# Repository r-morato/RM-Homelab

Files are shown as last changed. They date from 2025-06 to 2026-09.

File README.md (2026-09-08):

# RM-Homelab




A compact, quiet, movable homelab in a custom 10-inch rack - two cables to run it
(power and Ethernet), enough capability to host the services I use every day, and
built so a single hardware failure or a bad upgrade doesn't take anything down for long.

This repo documents **how it works**: the cluster, the storage and replication model,
backups, the automation that patches everything, and the security choices. It is written
so I can rebuild from it.

> **Addresses and hostnames in this repo are sanitised.** `10.0.0.x` is the LAN /
> management segment, `10.0.1.x` the storage + cluster segment, and hostnames are
> generic labels (`pve-node-1`, `ct-dashboard`, …). Real values live only in a
> gitignored inventory on the host.

## Why build it

I wanted one place to learn, experiment, and self-host - with real control over my data
and no monthly bill for things I can run myself. The constraints that shaped every
decision: **low noise** (it lives near people), **low power**, **physically mobile**
(hence wheels), and **cheap** - no enterprise hardware. Not the most powerful lab; the
sweet spot between capability, cost, and cleanliness.

## What it is now

- **2-node Proxmox VE cluster** (a Lenovo ThinkCentre M720q and an HP EliteDesk 800
  mini-PC) with an external **QDevice** on the NAS for quorum.
- **High availability across every running guest** - lose a node and everything restarts
  on the other in a few minutes, then moves home when the node returns.
- **Shared storage over NFS from the NAS** - guest disks live there so either node can
  run any guest.
- **Nightly backups to the NAS** - `vzdump` for the stateful containers, a daily
  host-config archive, and a database-consistent dump for the one guest that needs it.
  Restores are tested.
- **Scheduled, hands-off patching** - a dedicated Ansible container with a
  [Semaphore](https://github.com/semaphoreui/semaphore) web UI patches the containers
  weekly and the hypervisors monthly, and pushes a summary to my phone. Reboots stay
  manual.
- **Hardened baseline** - key-only SSH with `fail2ban`, the Docker API on a local socket
  only, secrets kept out of git, and a staged firewall rollout.

## Documentation

| | |
|---|---|
| [Architecture](docs/architecture.md) | how it all fits together - nodes, guests, storage, boot order |
| [High availability & replication](docs/high-availability.md) | quorum on 2 nodes, HA failover, planned-maintenance drains |
| [Storage](docs/storage.md) | the NFS / local-lvm / media-NAS tiers and the trade-offs |
| [Networking](docs/networking.md) | the two segments, addressing, DNS, the corosync caveat |
| [Backups](docs/backups.md) | the `vzdump` job, host-config backup, the DB hook, restore test |
| [Automation](docs/automation.md) | the Ansible + Semaphore control container and repo |
| [Automated patching](docs/patching.md) | the "patch on schedule, notify-to-reboot" model |
| [Provisioning & configuration](docs/provisioning.md) | how a new guest is built and wired in |
| [Security](docs/security.md) | SSH, isolation, service exposure, the firewall plan |
| [Ansible playbooks](ansible/) | the actual automation code, with its own README |
| [Rack build](rack-build.md) | the custom 10-inch enclosure |
| [Hardware](hardware/) · [Software](software/) | per-component notes |
| [Diagrams](diagrams/) · [3D prints](3d_prints/) | network + cluster diagrams, printed mounts |

## Hardware at a glance

| Component | Role |
|---|---|
| Lenovo ThinkCentre M720q Tiny | Proxmox VE cluster node 1 (primary) |
| HP EliteDesk 800 (Mini) | Proxmox VE cluster node 2 (failover) |
| NAS (mirrored disks) | NFS shared storage, backup target, corosync QDevice |
| Raspberry Pi 4 | Home Assistant OS (bare metal, outside the cluster) |
| ESP32 + e-ink display | Proxmox stats display on the rack |
| Mac Mini | jump box / daily driver |
| TP-Link TL-SG108S | 8-port gigabit switch (unmanaged) |
| Eero Mesh 6 | router / gateway / Wi-Fi |
| APC Back-UPS 300W | battery backup |
| Oimaster HE-2006 + PCIe SATA card | hot-swap SSD bays |
| Hive Hub | heating control (Home Assistant integration) |

Full notes in [`hardware/`](hardware/) and [`rack-build.md`](rack-build.md).

## Lessons learned

- **Noise matters more than you think** when servers live near bedrooms.
- **Cheap gear goes surprisingly far** if you're willing to tinker.
- **Power and thermals aren't optional** - the SSDs show a high unclean-shutdown count,
  which is why a UPS with automatic graceful shutdown is near the top of the list.
- **A 2-node cluster needs a third vote.** Without the QDevice, losing either node
  freezes the survivor. With it, failover is a non-event.
- **`curl | bash` from someone else's `main` branch, as root, on a schedule** is a bad
  idea however convenient - replacing it with version-controlled Ansible was worth it.
- **Snapshots and tested restores turn mistakes into footnotes.**

## Roadmap

- Off-NAS / offsite copy of the backup archives (currently the biggest gap).
- Finish the staged Proxmox firewall rollout (see [security](docs/security.md)).
- Second corosync link so the heartbeat doesn't share one wire with NFS.
- Move small stateful containers onto local storage for snapshot-mode backups.
- 2FA on the Proxmox admin account and Semaphore.
- Dynamic Ansible inventory from the PVE API.
- More Home Assistant sensors and automations.

## License

[MIT](LICENSE) © Roger Morato

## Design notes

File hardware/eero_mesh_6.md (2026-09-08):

# Eero Mesh 6 - router / gateway

The perimeter router and Wi-Fi for the whole house, including the lab. `10.0.0.1` on the
LAN segment.

## Role

* **Gateway / NAT** - the only path to the internet.
* **DHCP** for dynamic clients; static infra addresses sit outside the pool.
* **Perimeter firewall** - the only packet filtering currently in effect (the Proxmox
  firewall is designed but not enabled - see [`docs/security.md`](../docs/security.md)).
* **Wi-Fi 6 mesh** for phones, laptops, smart-home gear, and the ESP32 display.

## Notes

* No ports are forwarded to the lab. Remote access is via
  [Guacamole](../software/guacamole.md) or a VPN.
* Its presence is picked up by Home Assistant for device presence detection.
* A dedicated x86 firewall/router appliance (OPNsense-class) is a long-standing "maybe"
  - it would also give real VLAN support.

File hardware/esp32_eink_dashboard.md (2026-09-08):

# ESP32 + e-ink Proxmox dashboard

A small battery-friendly wall display on the rack that shows cluster stats at a glance - node load, memory, guest count, backup age - without opening a browser.

## Build

| | |
|---|---|
| MCU | ESP32 (Wi-Fi) |
| Display | e-ink panel - near-zero power when static, readable in any light |
| Power | USB from the rack's 6-port charger |
| Mount | custom 3D-printed bracket sized to the panel (not yet published) |

## How it works

The ESP32 connects to Wi-Fi, calls the **Proxmox VE API** read-only (a dedicated token
user with view-only permissions), parses the JSON, and redraws the e-ink panel on an
interval. Between refreshes it deep-sleeps, so it sips power.

It is **outside the cluster** and purely a consumer of the API - nothing depends on it,
and it has no write access.

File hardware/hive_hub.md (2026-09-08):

# Hive Hub - heating control

The manufacturer hub for the home's Hive smart heating (thermostat + schedule). Powered
from the rack's 6-port USB charger, sat on top of the rack to keep its radio clear of
the metal.

## Role

* Talks to the Hive thermostat and receiver over its own radio.
* Bridged into [Home Assistant](../software/homeassistant.md) via the Hive integration,
  so heating is part of presence- and schedule-driven automations rather than a
  separate app.

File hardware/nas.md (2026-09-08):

# NAS - shared storage, backup target & QDevice

A low-power, always-on network-attached storage box that does three jobs for the
cluster. It is the most load-bearing single device in the lab.

## The three roles

1. **Shared storage over NFS.** It exports a filesystem that both cluster nodes mount as
   `PROX-NFS`. Every guest's root disk is a raw image on that export - which is what lets
   either node start any guest, and therefore what makes HA failover possible on a
   cluster with no shared block storage. See [storage](../docs/storage.md).
2. **Backup target.** The nightly `vzdump` archives and the daily host-config archives
   land on the same export. See [backups](../docs/backups.md).
3. **Cluster QDevice.** It runs `corosync-qnetd`, providing the third quorum vote so the
   2-node cluster stays quorate when a node is down. See
   [high availability](../docs/high-availability.md) and [`qdevice-host.md`](qdevice-host.md).

## Configuration

| | |
|---|---|
| Disks | 2 × HDD, **mirrored** (RAID-1) |
| OS media | separate from the data array - a card / small device, so the data survives an OS-media failure and can be re-assembled independently |
| Filesystem | EXT4 on the mirror |
| Network | on the storage/cluster segment (`10.0.1.x`); NFS export is restricted to that subnet |
| Free space | ~800 GB headroom for backups |

## Why this is a deliberate risk

Mirrored disks protect against a **drive** failure. They do not protect against the
**box** failing, a filesystem bug, or an accidental delete - and if this box goes down,
every guest's root disk vanishes at once and the NFS mount blocks (`hard` mount) until
it's back.

This is accepted because the box has been reliable, restores onto local storage are
tested, and the control container that can rebuild everything is deliberately **not** on
NFS. The open mitigation is a copy of the backup archives that doesn't live on this box - see the gap noted in [storage](../docs/storage.md) and [backups](../docs/backups.md).

## A second NAS

There is a second, larger NAS for the bulk media library, bind-mounted into the media
containers. It is currently **offline**; it is also the intended destination for the
off-box backup copy once it's back in service.

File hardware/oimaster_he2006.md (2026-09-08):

# Oimaster HE-2006 - 4-slot hot-swap SATA cage

A 4-bay internal hot-swap drive cage (3.5" slots, 2.5" SSDs via adapters, individual
power indicators) fitted to [`pve-node-1`](thinkcentre_m720q.md).

## Role

Gives the ThinkCentre - which has almost no internal drive room - accessible,
tool-less SATA bays for 2.5" SSDs, connected through the
[PCIe SATA card](pcie_sata_card.md).

## Notes

The cluster's live guest disks are on **NFS from the [NAS](nas.md)**, and each node
boots from its internal NVMe, so these bays are spare capacity / local scratch rather
than primary storage. They're the obvious place to land guest disks if the design moves
stateful containers onto local storage (see [`docs/storage.md`](../docs/storage.md)).

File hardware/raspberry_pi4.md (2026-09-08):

# Raspberry Pi 4 - Home Assistant

A Raspberry Pi 4 (8 GB) running **Home Assistant OS on bare metal**, powered from the
rack's 6-port USB charger and mounted in a custom 3D-printed 10-inch bracket.

## Why bare metal, outside the cluster

Home automation should keep working while the Proxmox cluster is being patched, rebooted,
or rebuilt - and it needs a stable USB path to the Zigbee coordinator. Running it on its
own dedicated board keeps it independent of everything else in the rack. It has its own
backup routine (HAOS snapshots) separate from the cluster's `vzdump` job.

## Role

* **Home automation hub** - the single control point for the house's smart devices.
* **Zigbee coordinator** - via a Sonoff Zigbee 3.0 USB Dongle Plus, for local
  (cloud-free) control of sensors, lights, and switches.

## Integrations

Zigbee (Sonoff dongle), Hive heating ([`hive_hub.md`](hive_hub.md)), Ecovacs, Ring,
Octopus Energy, LG webOS TV, Spotify, Tuya, the Eero router (presence detection), and
the Home Assistant mobile apps. Plus the usual core integrations (`sun`, `met` weather,
`cast`, Supervisor, `backup`).

See [`software/homeassistant.md`](../software/homeassistant.md) for the platform side.

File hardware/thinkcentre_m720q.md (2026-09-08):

# Lenovo ThinkCentre M720q Tiny - `pve-node-1`

The primary node of the [Proxmox VE cluster](../software/proxmox.md). An ultra-compact
1-litre business desktop - quiet, low-power, and cheap on the used market, which is the
whole point of this build.

## Role

* **Primary cluster node.** The HA node-affinity rule prefers it, so all guests normally
  run here and [`pve-node-2`](pve-node-2.md) sits idle as failover.
* Hosts the integrated GPU that [`ct-media-a`](../software/jellyfin.md) and
  [`ct-media-b`](../software/plex.md) share for hardware transcoding.
* Runs the daily host-config backup timer (see [backups](../docs/backups.md)).

## Configuration

| | |
|---|---|
| CPU | 6-core Intel (no hyper-threading) |
| RAM | 16 GiB DDR4 SODIMM |
| Boot / local storage | single consumer NVMe SSD - LVM root + swap + `local-lvm` thin pool |
| Extra SATA | PCIe → 4-port SATA card into the [Oimaster HE-2006](oimaster_he2006.md) bays |
| Network | onboard NIC (LAN, `vmbr0`) + a second NIC (storage/cluster, `vmbr1`) |
| OS | Proxmox VE 9.2 on Debian 13 |

## Notes

* **Single SSD = no local redundancy.** This is tolerated because the guests' disks live
  on the [NAS](nas.md) over NFS and are backed up; the node itself is reproducible from
  the host-config archive.
* The SSD's SMART data is healthy (low wear, zero media errors) but shows a **high
  unclean-shutdown / power-cycle count** - the reason a UPS with automatic graceful
  shutdown is on the roadmap. See [`apc_ups.md`](apc_ups.md).
* Mounted in the rack on a custom 3D-printed tray - see [`3d_prints/`](../3d_prints/).

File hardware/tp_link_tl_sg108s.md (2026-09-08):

# TP-Link TL-SG108S - 8-port gigabit switch

The wired core of the rack. Unmanaged, plug-and-play, gigabit on all 8 ports.

## Role

Connects everything wired: both cluster nodes (two cables each - one per segment), the
NAS (two cables), the Raspberry Pi, the Mac Mini, and the uplink to the
[Eero](eero_mesh_6.md).

## Consequence of it being unmanaged

No VLANs. The "LAN" and "storage/cluster" segments
([`docs/networking.md`](../docs/networking.md)) therefore share **one L2 broadcast
domain** - separation is logical (different subnets, and each node uses a specific NIC
for storage/corosync traffic), not true isolation. A managed switch with VLANs, or a
direct node-to-node link for corosync, is on the roadmap.

At 8 ports it is also nearly full - the next expansion needs a bigger switch anyway.

## Mounting

Custom 3D-printed 10-inch bracket - see [`3d_prints/`](../3d_prints/).

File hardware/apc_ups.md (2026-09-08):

# APC Back-UPS (300 W / 0.5 kVA)

Line-interactive UPS on the critical leg of the rack: the two cluster nodes, the switch,
the router, and the NAS. It rides out brownouts and short outages and gives everything
time for a clean shutdown on a long one.

## Current state

* **Battery backup and surge protection: working.** A brief power blip is invisible to
  the lab.
* **Automatic graceful shutdown: not wired up yet.** It used to be driven over USB from
  the (now offline) media NAS acting as a master and signalling Proxmox. With that box
  down, there is no automatic "power's been out for N minutes, shut down now" path.

The nodes' SSDs show a high unclean-shutdown count, so restoring this is a priority.

## Plan

Connect the UPS's USB to one cluster node, run **NUT** (`nut-server` there,
`nut-client` on the other node and the NAS), and configure a shutdown policy: on
"battery low" or after a set time on battery, HA guests stop, then the nodes power off.
Everything comes back on its own when mains returns and the nodes `onboot` their guests.

## Powered by the UPS

ThinkCentre (`pve-node-1`), HP EliteDesk (`pve-node-2`), TP-Link switch, Eero router,
NAS. The Raspberry Pi and low-power accessories are on the non-UPS leg.

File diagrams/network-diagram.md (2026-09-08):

# Network diagram

Logical topology. Addresses are sanitised: `10.0.0.x` = LAN / management,
`10.0.1.x` = storage + cluster. See [`docs/networking.md`](../docs/networking.md).

```mermaid
flowchart TB
    ISP([Internet]) --- Router["Eero Mesh 6<br>router / gateway · 10.0.0.1"]
    Router --- SW["TP-Link SG108S<br>8-port unmanaged switch"]

    subgraph LAN["LAN / management - 10.0.0.0/24 (vmbr0)"]
        N1LAN["pve-node-1 · 10.0.0.11"]
        N2LAN["pve-node-2 · 10.0.0.12"]
        Guests["LXC guests<br>10.0.0.100-112"]
        Pi["Raspberry Pi 4<br>Home Assistant OS"]
        ESP["ESP32 e-ink<br>Proxmox stats (Wi-Fi)"]
    end

    subgraph STOR["storage + cluster - 10.0.1.0/24 (vmbr1)"]
        N1S["pve-node-1 · 10.0.1.11"]
        N2S["pve-node-2 · 10.0.1.12"]
        NAS["NAS · 10.0.1.40<br>NFS export + corosync-qnetd (QDevice)"]
    end

    SW --- N1LAN
    SW --- N2LAN
    SW --- Guests
    SW --- Pi
    Router -. Wi-Fi .- ESP
    SW --- N1S
    SW --- N2S
    SW --- NAS

    N1S -- "NFS: guest root disks + backups" --- NAS
    N2S -- NFS --- NAS
    N1S -. "corosync ring + QDevice vote" .- NAS
    N2S -. corosync .- NAS
    N1S === N2S

    ESP -. "PVE API (read-only)" .-> N1LAN
```

Legend: solid = data path, dotted = cluster / control traffic, `===` = corosync between
the two nodes.

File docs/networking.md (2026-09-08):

# Networking

## Two segments, on purpose

| Segment | Subnet (sanitised) | Bridge | Carries |
|---|---|---|---|
| LAN / management | `10.0.0.0/24` | `vmbr0` | guest traffic, the web UIs, SSH, the automation container → targets |
| Storage + cluster | `10.0.1.0/24` | `vmbr1` | NFS to the NAS, corosync, the QDevice vote |

Each node has a physical NIC on each segment. Keeping storage and cluster traffic off
the LAN means a busy download or a Plex transcode pulling from the NAS doesn't compete
with the corosync heartbeat for the same wire - mostly. See the known limitation below.

```
   Router ── Switch ─┬─ pve-node-1 vmbr0 (10.0.0.11)  ── guests, mgmt
                     │  pve-node-1 vmbr1 (10.0.1.11)  ── NFS + corosync
                     ├─ pve-node-2 vmbr0 (10.0.0.12)
                     │  pve-node-2 vmbr1 (10.0.1.12)
                     ├─ NAS         (10.0.1.40)        ── NFS export + corosync-qnetd
                     ├─ Raspberry Pi 4 (10.0.0.x)      ── Home Assistant
                     └─ ESP32 e-ink   (Wi-Fi)          ── Proxmox stats display
```

## Guest addressing

Guests are on `vmbr0` with static addresses in `10.0.0.100`-`10.0.0.112`, chosen to
match the Proxmox VMID (guest `104` is `10.0.0.104`). It makes the inventory readable
and means you can guess a guest's address from its ID. The automation container is
`10.0.0.109`.

## The router and DNS

* The perimeter router / gateway is an **Eero mesh** (`10.0.0.1`) doing DHCP for
  dynamic clients, NAT, and the basic firewall. Static infra addresses are outside the
  DHCP pool. See [`hardware/eero_mesh_6.md`](../hardware/eero_mesh_6.md).
* **Pi-hole** provides LAN DNS and ad/tracker filtering; clients are pointed at it
  either by DHCP option or per-device. See [`software/pihole.md`](../software/pihole.md).
* The 8-port unmanaged switch ([`hardware/tp_link_tl_sg108s.md`](../hardware/tp_link_tl_sg108s.md))
  is the wired core. Because it's unmanaged there are **no VLANs**: the two segments
  share one L2 broadcast domain, and the separation is only logical - different subnets,
  and each node using a specific NIC for storage/corosync. True isolation (a managed
  switch + VLANs, or a direct node-to-node corosync link) is a roadmap item.

## Corosync - the known weak spot

Corosync currently runs a **single ring** on the storage segment. That is a
simplification worth calling out:

* If that link flaps, or NFS saturates it badly enough to delay heartbeats, corosync
  sees a membership change even though both nodes are healthy.
* **Roadmap:** add a second `knet` link on the LAN segment so corosync has a fallback
  path, and ideally make a dedicated NIC the primary ring.

Until then the QDevice is what keeps a spurious membership blip from turning into a
loss of quorum - see [high availability](high-availability.md).

## Firewall posture

The Proxmox firewall is being rolled out in stages - datacenter default-deny inbound,
management ports restricted to one subnet, per-guest app-port rules - described in
[security](security.md). Perimeter filtering is handled by the Eero in the meantime.

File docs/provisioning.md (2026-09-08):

# Provisioning & configuration

How a new service goes from "I want to run X" to "X is running, backed up, HA-managed,
and patched on schedule."

## Guest defaults

Every guest is an **unprivileged LXC container**. VMs are avoided unless something needs
its own kernel - containers are lighter, boot in a second, and share the host's patched
kernel.

| Setting | Default | Notes |
|---|---|---|
| Type | unprivileged LXC | UID-remapped; a root break-out lands as an unprivileged host UID |
| `onboot` | `1` | HA starts it anyway, but this covers a single-node boot |
| `features` | `nesting=0,keyctl=0` | **only** the Docker host gets `nesting=1` |
| Root disk | raw image on `PROX-NFS` | so either node can start it - except the control container, which is on `local-lvm` |
| Network | static on `vmbr0`, `10.0.0.<vmid>` | address matches the VMID |
| Firewall | `firewall=1` | per-guest firewall enabled (rules come with the firewall rollout) |

The current fleet is a mix of Debian 13 / 12 and Ubuntu 24.04. New guests are Debian 13.

## Steps to add a service

1. **Create the container** - from the Debian 13 template, with the defaults above.
   `ct-dashboard`-style config lives in the container; nothing about the app goes in the
   Proxmox guest config except a Notes reference (see below).
2. **Put it under HA** - `ha-manager add ct:<id> --state started`, then add `ct:<id>` to
   the node-affinity rule so it prefers `pve-node-1` with `pve-node-2` as failover. See
   [high availability](high-availability.md).
3. **Add it to backups if it holds unique state** - add the VMID to the nightly `vzdump`
   job and to the `backup_protected` group in the Ansible inventory. Streaming /
   download / indexer containers are deliberately left off - see [backups](backups.md).
4. **Wire up the automation** - add it to `inventory/hosts.yml` (and the Semaphore static
   inventory), authorise the control-container key, add the `20-ansible.conf` sshd
   drop-in if the guest uses `AllowUsers`. Full steps in [automation](automation.md).
5. **Harden its SSH** - key-only root, `PasswordAuthentication no`, `fail2ban`. See
   [security](security.md).

## The Notes-field convention

Each guest's Proxmox **Notes** field carries a short plaintext reference - the service
URL and port, the config path inside the container, and a pointer to where credentials
are kept (a password manager). It does **not** carry the credentials themselves.

Notes fields are visible through the web UI and API and are included in every config
backup, so anything written there should be treated as non-secret. The rule: Notes
describe *where things are*, never *what the secrets are*.

## GPU passthrough (media containers)

`ct-media-a` (Jellyfin) and `ct-media-b` (Plex) share the host's integrated GPU for
hardware transcoding: the render device is bind-mounted into the container and the
container's media user is put in the right group. Both containers can use it at once
(it's shared, not exclusive-passthrough), which is fine for a couple of simultaneous
transcodes.

## Bind mounts

The media containers bind-mount the bulk media library from the (currently offline)
media NAS. A bind mount is host-path → container-path and is set on the guest config,
so it has to exist on **whichever node runs the guest** - worth remembering for HA
failover.

## Configuration management, honestly

Application configuration inside the containers is currently **hand-managed** - set up
once, then patched in place. Ansible manages the *fleet* (patching, SSH, soon firewall
rules) but not per-app config. Bringing individual services under a role
(`deploy_docker_service`-style) is a direction, not a current state.

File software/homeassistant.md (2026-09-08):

# Home Assistant

Open-source, local-first home automation platform - the central brain for the house's
smart devices. Runs on **Home Assistant OS, bare metal, on a dedicated
[Raspberry Pi 4](../hardware/raspberry_pi4.md)** - deliberately **outside** the Proxmox
cluster.

## Why it's not a cluster guest

* Home automation should keep working while the cluster is being patched or rebuilt.
* It needs a stable, exclusive USB path to the Zigbee coordinator - cleaner on dedicated
  hardware than passed through to a container.
* It has its own backup story (HAOS snapshots), independent of the cluster's `vzdump`.

## Role

* **Single control surface** for every smart device, regardless of brand.
* **Local Zigbee network** via a Sonoff Zigbee 3.0 USB Dongle Plus - sensors, lights,
  switches, no cloud round-trip.
* **Automation engine** - presence- and sensor-driven routines (heating, lighting,
  notifications).
* **Dashboards & history** for sensor data and energy use.

## Integrations

Zigbee, Hive heating, Ecovacs, Ring, Octopus Energy, LG webOS TV, Spotify, Tuya, the
Eero router (presence), and the Home Assistant mobile apps.

## Relationship to the lab

Monitored by [Uptime Kuma](uptimekuma.md); resolves DNS through [Pi-hole](pihole.md).
Otherwise self-contained.

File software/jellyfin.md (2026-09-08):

# Jellyfin

Open-source media server. Runs in `ct-media-a` (VMID 102).

## Role

* Streams the media library (stored on the media NAS, bind-mounted into the container)
  to clients on the LAN and remotely.
* The free/self-hosted counterpart to [Plex](plex.md) - both run so I'm not tied to one.

## Notes

* **Hardware transcoding** via the host's integrated GPU - the render device is
  bind-mounted into the container. [`ct-media-b`](plex.md) shares the same GPU.
* **Not on the backup job.** The library lives on the media NAS; Jellyfin's own metadata
  DB is re-buildable by a library scan. Nothing here is worth an archive.
* HA-managed. If it moves to `pve-node-2`, that node needs the media bind-mount too -   see [provisioning](../docs/provisioning.md).

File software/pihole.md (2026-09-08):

# Pi-hole

Network-wide DNS sinkhole - LAN DNS resolver plus ad/tracker blocking for every device
that uses it.

## Role

* **LAN DNS** - clients resolve through it (set by DHCP option on the router, or
  per-device). Upstream is a public resolver.
* **Filtering** - blocks ad/tracker/malware domains from common block-lists.
* **Visibility** - query log and per-client stats in its web UI.

## Hosting

Runs as a container on the [Docker host](docker-host.md) (`ct-docker`), so it inherits
that container's HA coverage and backup.

## Notes

* DNS is a dependency for most of the lab, so it matters that its host is HA-managed -   a node failure shouldn't take name resolution with it.
* Block-lists and local DNS records are lightweight config; they're captured in the
  `ct-docker` backup.

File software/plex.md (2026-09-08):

# Plex Media Server

Client-server media system. Runs in `ct-media-b` (VMID 103).

## Role

* Organises and streams the film/TV library (on the media NAS, bind-mounted in) to smart
  TVs, phones, tablets, and browsers, on the LAN and remotely.
* Runs alongside [Jellyfin](jellyfin.md) - Plex for polish and client support, Jellyfin
  as the no-strings fallback.

## Notes

* **Hardware transcoding** via the host iGPU, shared with the Jellyfin container.
* **Not on the backup job.** Media is on the NAS; the Plex database is a metadata cache
  that rebuilds from a library scan.
* HA-managed; needs the media bind-mount on whichever node runs it.

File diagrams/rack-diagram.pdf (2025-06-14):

FRONT | BACK

EERO ROUTER
Hive hub
8 | 8
Monitor | POWER STRIP 1 (4 plug)
Eero Router | Linux Server | NAS | Power Strip 2
7 | 7 Brush unit | Cable manager

Patch panel

6 | 6

SWITCH

5 | 5
RASPBERRY 1 | RASPBERRY 2
4 | 4
3 | 3 Cable manager Lenovo m740q
2 | 2 POWER STRIP 2 (4 plug) Mac
Switch | Raspberry Pair | N/A | N/A
1 | 1
QNAP/UPS | QNAP/UPS

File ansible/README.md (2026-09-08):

# Patching automation (Ansible + Semaphore)

Automated OS patching for the Proxmox VE cluster and its LXC guests, driven from a
dedicated control container and a [Semaphore](https://github.com/semaphoreui/semaphore)
web UI.

It replaces an earlier weekly cron on a hypervisor that did
`bash -c "$(curl -fsSL https://.../update-lxcs-cron.sh)"` as root - an unpinned
`curl | bash` from a third-party repo, with no pre-backup and no report. See
[`../docs/automation.md`](../docs/automation.md) and
[`../docs/patching.md`](../docs/patching.md) for the design write-up; this README is the
operator reference.

---

## 1. Architecture

```
                        ┌─────────────────────────────┐
                        │  control container          │
                        │  Debian 13, 1 vCPU / 512 MB  │
                        │  on local-lvm (not NFS)      │
                        │                              │
                        │  ├─ ansible-core             │
                        │  ├─ this repo → /opt/ansible  │
                        │  └─ Semaphore (web UI :3000)  │
                        └──────────────┬───────────────┘
                                       │  SSH as root, key-only,
                                       │  key locked from="<control IP>"
                ┌──────────────────────┼───────────────────────┐
                │                      │                       │
       ┌────────▼─────────┐   ┌────────▼─────────┐    ┌─────────▼────────┐
       │  pve-node-1      │   │  pve-node-2      │    │  LXC guests      │
       │  (pve_nodes)     │   │  (pve_nodes)     │    │  (lxc_guests)    │
       └──────────────────┘   └──────────────────┘    └──────────────────┘
```

* The control container reaches every target over the **LAN segment**, never the
  storage/cluster segment - corosync runs there as a single ring and management
  traffic is kept off it.
* The control container holds root SSH access to the entire cluster, so it is the most
  sensitive guest: unprivileged, `nesting=0,keyctl=0`, key-only SSH, per-guest firewall
  enabled, and every authorised key is `from="<control IP>"`-restricted.
* It sits on `local-lvm`, so it still runs (and can still patch the guests) during an
  NFS outage.

## 2. What runs when

| Job | Playbook | Schedule (Semaphore) | Disruptive? |
|---|---|---|---|
| Patch containers | `playbooks/patch-guests.yml` | weekly, Sat 02:00 | pre-backup + `dist-upgrade` in place; no reboot (opt-in `-e allow_reboot=true`) |
| Patch hypervisors | `playbooks/patch-hosts.yml` | monthly, 1st Sun 03:00 | `dist-upgrade` **in place** - no reboot, no HA drain, guests untouched; reports "reboot required" |
| Reboot hypervisors | `playbooks/reboot-hosts.yml` | **manual only** | drains HA + reboots, one node at a time; won't touch the node hosting the control container |
| Connectivity check | `playbooks/ping.yml` | on demand | none |

This is the **"patch on schedule, notify-to-reboot"** model: package updates land
automatically and non-disruptively; a hypervisor reboot is always a deliberate,
hands-on action.

## 3. Repository layout

```
ansible/
├── ansible.cfg                 # inventory path, ssh tuning, stdout callback
│                               # (no requirements.yml at root - collections come
│                               #  from the Debian `ansible` package; see docs/)
├── inventory/
│   ├── hosts.example.yml       # committed, placeholder addresses
│   └── hosts.yml               # gitignored - the real inventory
├── roles/
│   ├── apt_upgrade/            # idempotent update+upgrade, records facts for the summary
│   ├── pve_node_patch/         # dist-upgrade a node in place, flag if a reboot is due
│   ├── pve_node_reboot/        # drain HA → reboot → wait quorum+pveproxy → un-drain
│   └── notify_webhook/         # POST a short {title,message} to the webhook, never fails
├── playbooks/
│   ├── group_vars/             # adjacent to the PLAYBOOKS so vars load whether the
│   │   ├── all.yml             #   run is from the CLI or from Semaphore (which uses
│   │   ├── pve_nodes.yml       #   its own inventory path). all.yml = apt + webhook +
│   │   └── lxc_guests.yml      #   backup defaults; the others tune per host class
│   ├── ping.yml
│   ├── patch-guests.yml        # pre-backup + patch all guests + notify
│   ├── patch-hosts.yml         # patch both nodes, serial 1, no reboot, notify
│   └── reboot-hosts.yml        # rolling reboot, manual
├── bootstrap/
│   ├── 01-create-control-node.sh    # run on a PVE node - builds the control container
│   ├── 02-deploy-control-node-key.sh # run on a PVE node - authorises it everywhere
│   └── semaphore/              # API scripts that recreate the Semaphore project objects
└── docs/
    ├── control-node.md         # build + harden the control container
    ├── semaphore.md            # install + configure Semaphore, projects, schedules
    └── requirements.reference.yml   # collections list (only needed on a non-Debian box)
```

## 4. How the tricky bits work

### Pre-patch backup (`patch-guests.yml`)

The first play runs once on the first node and calls `vzdump` for exactly the containers
in the `backup_protected` inventory group (the ones already on the nightly job), in
snapshot mode. A bad upgrade is then one `pct rollback` away. Skip it with
`-e pre_patch_backup=false`.

### A dead third-party repo doesn't wedge the run

`apt-get update` returns `100` when *some* repositories fail but others succeed. The
`apt_upgrade` role tolerates rc `100`, patches everything the working repos provide, and
carries the failing lines into the run summary as `[repo warnings]`. Any other rc
(network down, dpkg lock) is still fatal.

### Patching a hypervisor (`pve_node_patch`)

`serial: 1`, and per node just `apt dist-upgrade` **in place**. No reboot, no HA drain - installing packages doesn't disturb running guests, and draining every guest to the
other node (and back) merely to install packages is both disruptive and self-defeating
here: the control container is itself an HA guest and would be migrated out from under
the running playbook. If a node ends up needing a reboot, the run says so.

### Rebooting a hypervisor (`pve_node_reboot`, manual only)

`serial: 1`, `any_errors_fatal`. Per node:

1. **Guard:** find where the control container is (`ha-manager status`); if it's on
   *this* node, fail immediately with instructions (rebooting it would kill the run).
   Bypass only with `-e control_node_relocated=true` after you've moved it yourself.
2. Reboot only if `/var/run/reboot-required` exists **or** the running kernel is older
   than the newest `/boot/vmlinuz-*` (override: `-e reboot_only_if_required=false`).
3. `ha-manager crm-command node-maintenance enable <node>` → poll until no
   `service … (<node>, …)` line remains.
4. `reboot`, wait for the node, then poll `pvecm status` for `Quorate: Yes` and
   `wait_for` port 8006.
5. `node-maintenance disable`; on the affinity-preferred node, poll until guests return.

This is the exact by-hand sequence from a kernel upgrade, codified - minus the part
where you have to remember not to strand yourself.

### Notifications

`notify_webhook` POSTs `{"title": …, "message": …}` to the URL in the real inventory (a
phone-push endpoint). Messages are hard-truncated to ~3.5 KB because that endpoint
returns HTTP 500 for bodies over ~5-7 KB. A failed notification is logged, never fatal.

## 5. First-time setup

See [`docs/control-node.md`](docs/control-node.md) then
[`docs/semaphore.md`](docs/semaphore.md). In short:

```bash
# on pve-node-1, as root
./bootstrap/01-create-control-node.sh           # build the control container
./bootstrap/02-deploy-control-node-key.sh        # authorise it everywhere

# copy this tree into the container (id 109 in the bootstrap script)
pct exec 109 -- install -d /opt/ansible
tar -C .. -cf - ansible | pct exec 109 -- tar -C /opt -xf -

# inside the container (collections ship with the Debian `ansible` package - no galaxy step)
cd /opt/ansible
cp inventory/hosts.example.yml inventory/hosts.yml   # then edit with real values
ansible-playbook playbooks/ping.yml                  # verify reachability
ansible-playbook playbooks/patch-guests.yml --check  # dry run
```

Then install Semaphore ([`docs/semaphore.md`](docs/semaphore.md)).

## 6. Day-to-day

```bash
ansible-playbook playbooks/patch-guests.yml                     # patch all containers
ansible-playbook playbooks/patch-guests.yml --limit ct-media-a  # just one
ansible-playbook playbooks/patch-hosts.yml                      # patch both nodes (no reboot)
ansible-playbook playbooks/reboot-hosts.yml                     # when a reboot was flagged
```

…or click **Run** on the matching task template in Semaphore.

### Rebooting the nodes

`patch-hosts.yml` never reboots and never drains - it just installs packages one node
at a time. When it reports a node needs a reboot, `reboot-hosts.yml` does the
drain → reboot → wait-for-quorum → un-drain cycle, **but it will not reboot the node
currently hosting the control container** (that would kill the run). On this 2-node
cluster:

```bash
ha-manager status | grep ct:109                             # find the control container
ansible-playbook playbooks/reboot-hosts.yml --limit <other> # reboot the other node
ha-manager migrate ct:109 <other>                           # move the control container
ansible-playbook playbooks/reboot-hosts.yml --limit <first> -e control_node_relocated=true
```

## 7. Adding a new container or node

For a new guest that should be patched:

1. **Inventory** - add it under `lxc_guests` in `inventory/hosts.yml` (and
   `backup_protected` if it's on the vzdump job). The playbooks iterate the group, so
   nothing else changes.
2. **Semaphore** uses a *static* copy of that inventory - update it too:
   Semaphore → project → Inventory → `production` → edit, or re-paste `hosts.yml`.
3. **SSH access** - `bootstrap/02-deploy-control-node-key.sh` (add the new id to
   `GUEST_IDS`) or a one-off `pct exec <id> -- ...` to drop the `from="<control IP>"`
   key into `root@`'s `authorized_keys`. If the guest has `AllowUsers` in sshd, add the
   `20-ansible.conf` drop-in (see `docs/control-node.md` §3a).
4. **HA** (recommended for anything that matters) - `ha-manager add ct:<id>
   --state started` and add `ct:<id>` to the node-affinity rule's `resources`.

> The step-2 double entry is the price of keeping `hosts.yml` out of git. If you add
> guests often, switch Semaphore to the `community.general.proxmox` **dynamic
> inventory** (queries the PVE API, auto-discovers every guest); group membership then
> comes from PVE tags. Not set up here yet.

## 8. Security notes

* `inventory/hosts.yml` (real addresses + webhook URL) and any `vault.yml` /
  `.vault_pass` are gitignored. Only `hosts.example.yml` with `10.0.0.x` placeholders is
  committed.
* The control container is a single point of compromise for the whole cluster. Treat
  its backups and its `/root/.ssh/id_ed25519_ansible` accordingly. It is on the nightly
  vzdump job and under HA.
* Authorised keys on targets are `from="<control IP>"`-locked; the plan is to tighten
  further once the Proxmox firewall is enabled, restricting SSH to the control
  container and one workstation. See [`../docs/security.md`](../docs/security.md).

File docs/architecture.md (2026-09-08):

# Architecture

This is the "how it all fits together" page. Individual subsystems get their own deep
dives - [high availability](high-availability.md), [storage](storage.md),
[networking](networking.md), [backups](backups.md), [automation](automation.md),
[patching](patching.md), [provisioning](provisioning.md), [security](security.md).

> **Addressing in this repo is sanitised.** `10.0.0.x` = the LAN / management segment,
> `10.0.1.x` = the storage + cluster segment, hostnames are generic labels
> (`pve-node-1`, `ct-dashboard`, …). The real values live only in a gitignored inventory
> on the host.

## The shape of it

```
                          ┌───────────────────────────── LAN / mgmt  10.0.0.0/24 ──┐
                          │                                                        │
   Internet ── Router ── Switch ──┬── pve-node-1 (Proxmox VE)  ── vmbr0            │
                                  │        │                                       │
                                  │        └── vmbr1 ──┐                           │
                                  │                     │  storage + cluster       │
                                  ├── pve-node-2 ───────┤  10.0.1.0/24             │
                                  │                     │                          │
                                  ├── NAS ──────────────┘  NFS export + corosync   │
                                  │        (guest root disks, backups, QDevice)    │
                                  │                                                │
                                  ├── Raspberry Pi 4  ── Home Assistant OS (bare)  │
                                  └── ESP32 e-ink  ── Proxmox stats display  ──────┘
```

Two mini-PCs run a **2-node Proxmox VE cluster**. A low-power **NAS** provides shared
storage over NFS *and* acts as the cluster's quorum tie-breaker. Everything else in the
rack is either a cluster guest or a standalone appliance (the Pi running Home Assistant,
the ESP32 display).

Design priorities, in order: **survive a single node failure without hands on
keyboard**, **never lose a guest to a bad disk or a bad upgrade**, and **keep routine
maintenance boring** (scheduled, reversible, self-announcing).

## The cluster nodes

| | `pve-node-1` | `pve-node-2` |
|---|---|---|
| Hardware | Lenovo ThinkCentre M720q Tiny | HP EliteDesk 800 (Mini), slightly less RAM |
| Role | primary - HA node-affinity prefers it | failover target |
| OS | Proxmox VE 9.2 on Debian 13 | same |
| Local disk | single NVMe SSD, LVM-thin pool (`local-lvm`) | same |

Both nodes are equal members of the cluster (`/etc/pve` is replicated live by pmxcfs).
`pve-node-1` is "primary" only in the sense that the HA placement rule prefers it, so
guests normally run there and `pve-node-2` sits mostly idle until it's needed.

See [`hardware/thinkcentre_m720q.md`](../hardware/thinkcentre_m720q.md) and
[`hardware/pve-node-2.md`](../hardware/pve-node-2.md).

## The guests

All guests are **unprivileged LXC containers**. There is one small utility VM; it is not
covered here.

| ID | Label | What it is | HA | Backed up |
|---|---|---|---|---|
| 100 | `ct-dashboard` | [Homepage](../software/homepage.md) start-page / dashboard | yes | yes |
| 101 | `ct-torrent` | download client ([media stack](../software/media-stack.md)) | yes | no |
| 102 | `ct-media-a` | [Jellyfin](../software/jellyfin.md) (iGPU transcode) | yes | no |
| 103 | `ct-media-b` | [Plex](../software/plex.md) (iGPU transcode) | yes | no |
| 104 | `ct-docker` | [Docker host](../software/docker-host.md) - Portainer, Uptime-Kuma | yes | yes |
| 105 | `ct-gateway` | [Apache Guacamole](../software/guacamole.md) remote-access gateway | yes | yes |
| 106-108 | `ct-indexer-a/b/c` | media indexer / automation ([media stack](../software/media-stack.md)) | yes | no |
| 109 | `ct-ansible` | [Ansible + Semaphore](../software/ansible.md) control container | yes | yes |
| 112 | `ct-app` | [small Laravel app](../software/app-container.md) | yes | yes |

"Backed up" = on the nightly `vzdump` job. The media-acquisition and streaming
containers are deliberately excluded - they hold no unique state worth an archive
(everything is re-downloadable or lives on the media NAS), and they are the largest and
noisiest to back up. See [backups](backups.md) for the reasoning.

Two containers - `ct-media-a` and `ct-media-b` - share the host's integrated GPU for
hardware transcoding.

## Storage layout

| Storage | Type | Holds |
|---|---|---|
| `local-lvm` (per node) | LVM-thin on the internal SSD | the control container; scratch; **restore target** |
| `PROX-NFS` | NFS export from the NAS | **every guest's root disk**, the backup archives, host-config backups |
| media NAS | second NAS (SMB/NFS), currently offline | bulk media, bind-mounted into the media containers |

Putting the guest root disks on NFS is what makes HA failover possible on a 2-node
cluster with no shared block storage - either node can start any guest because the disk
image is reachable from both. The cost is that the NAS is a broad single point of
failure. Both sides of that trade-off are discussed in [storage](storage.md).

## What happens on power-on

1. Both nodes boot Proxmox VE and form the cluster; the NAS's `corosync-qnetd` provides
   the third quorum vote.
2. The NFS export from the NAS is mounted on both nodes as `PROX-NFS`.
3. The HA manager starts every managed guest on its preferred node (`pve-node-1`).
4. `unattended-upgrades` and the Semaphore schedules take over routine patching from
   there; the `vzdump` timer fires nightly at 02:30.

If `pve-node-1` never comes back, step 3 happens on `pve-node-2` instead - see
[high availability](high-availability.md).

## Standalone appliances (not in the cluster)

* **Raspberry Pi 4** - runs Home Assistant OS on bare metal. Deliberately independent of
  the cluster so home automation keeps working during cluster maintenance. See
  [`software/homeassistant.md`](../software/homeassistant.md).
* **ESP32 + e-ink display** - pulls Proxmox stats over the API and shows them on a
  low-power screen on the rack. See
  [`hardware/esp32_eink_dashboard.md`](../hardware/esp32_eink_dashboard.md).

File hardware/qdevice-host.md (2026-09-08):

# Cluster QDevice

Not a separate box - the QDevice role runs on the [NAS](nas.md). This page is about the
role.

## What it does

A 2-node Proxmox cluster has 2 quorum votes. Lose a node and the survivor has 1 of 2,
which is not a majority: `/etc/pve` goes read-only and the HA manager won't start
anything. A **QDevice** adds a third vote from a machine that isn't a cluster node, so
losing one node still leaves 2 of 3 - a majority - and everything keeps working.

The NAS runs `corosync-qnetd`. Each node runs `corosync-qdevice`, which connects to it
and casts the extra vote on the node's behalf.

## Where it lives

* On the **storage / cluster segment** (`10.0.1.x`), the same network corosync uses.
* `corosync.conf` points at it via `quorum.device.net.host`. If that address changes,
  update the file and bump `config_version` - pmxcfs then syncs it to both nodes, and
  each node's `corosync-qdevice` service is restarted.

## Verifying

```bash
pvecm status
# Expect:  Quorate: Yes
#          Total votes: 3
#          Qdevice line showing 1 vote with flags "A,V" (Alive, Voting)
```

On the NAS: `corosync-qnetd-tool -l` shows both nodes connected and on the same
`config_version`.

## Failure behaviour

| Down | Votes | Quorate? |
|---|---|---|
| nothing | 3 / 3 | yes |
| one node | 2 / 3 | yes - HA acts |
| the QDevice (NAS) | 2 / 3 | yes - but now a single-node loss would freeze the cluster, so fix it before touching a node |
| a node **and** the QDevice | 1 / 3 | no - cluster frozen |

The historical failure here was subtler than an outage: the config pointed at an
**old address** of the NAS that no longer existed, so `corosync-qdevice` looped on a
failed connection and the device contributed **zero votes** while still showing as
"present". A one-line address fix restored the third vote.

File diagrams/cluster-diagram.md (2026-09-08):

# Cluster, quorum & HA diagram

How the 2-node cluster stays quorate and how guests fail over. See
[`docs/high-availability.md`](../docs/high-availability.md).

## Quorum - 3 votes across 3 boxes

```mermaid
flowchart LR
    subgraph Cluster
        N1["pve-node-1<br>1 vote · HA-preferred"]
        N2["pve-node-2<br>1 vote"]
        N1 === N2
    end
    QD["NAS<br>corosync-qnetd<br>1 vote"]
    N1 -. QDevice .- QD
    N2 -. QDevice .- QD

    R["Lose any one box → 2 of 3 votes → still quorate → HA still acts"]
```

## Normal state vs. node failure

```mermaid
flowchart TB
    subgraph Normal
        A1["pve-node-1<br>runs all 9 HA guests"]
        A2["pve-node-2<br>idle"]
        NFS1[("PROX-NFS<br>guest root disks")]
        A1 --- NFS1
        A2 --- NFS1
    end

    subgraph "pve-node-1 fails"
        B1["pve-node-1<br>DOWN (self-fenced via watchdog, ~1 min)"]
        B2["pve-node-2<br>quorate with QDevice → starts all 9<br>from PROX-NFS (~2-5 min)"]
        NFS2[("PROX-NFS")]
        B2 --- NFS2
    end

    subgraph "pve-node-1 returns"
        C1["pve-node-1<br>rejoins → HA fails guests back (preferred)"]
        C2["pve-node-2<br>idle again"]
    end

    Normal --> B1
    B1 --> C1
```

Failover works because there is only ever **one copy** of each guest disk, on NFS, and
both nodes mount it - no replication, no sync lag. The cost is that the NAS is a shared
single point of failure; see [`docs/storage.md`](../docs/storage.md).

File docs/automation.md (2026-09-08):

# Automation (Ansible + Semaphore)

All fleet-wide changes - OS patching today, more over time - run from **one dedicated
container** through **Ansible**, with **Semaphore** providing a web UI, schedules, and
run history. The playbooks and roles are version-controlled in
[`../ansible/`](../ansible/); that directory has its own
[operator README](../ansible/README.md).

## Why it exists

The lab used to patch its containers with a weekly cron on a hypervisor:

```
bash -c "$(curl -fsSL https://raw.githubusercontent.com/<third-party>/main/.../update-lxcs-cron.sh)"
```

That fetches whatever is at a third-party repo's `main` branch *at that moment* and runs
it as root on the hypervisor - no version pin, no checksum, no local copy, all output
discarded. Anyone who could land a commit in that repo (or intercept the fetch) would
get root on the cluster within a week. It also ran `apt dist-upgrade` in every container
with no pre-backup and no report.

The replacement keeps the convenience (scheduled, hands-off patching) and removes the
sharp edges: **code you control, under version control, with a pre-backup, a result
notification, and a full run log.**

## The control container

`ct-ansible` (VMID 109) - see [`software/ansible.md`](../software/ansible.md):

* **Unprivileged, minimal** Debian 13 LXC, 1 vCPU / 512 MB, `nesting=0,keyctl=0`,
  per-guest firewall on.
* **On `local-lvm`, not NFS** - so it still runs, and can still patch and rebuild the
  fleet, during a storage outage.
* **HA-managed** and on the nightly backup job - it is now important infrastructure.
* Holds a dedicated SSH keypair (`id_ed25519_ansible`, no passphrase - it runs
  unattended) that is authorised as **root** on every guest and on the peer node.
* It is the **single most sensitive guest in the lab**: whoever holds it holds root
  everywhere. Hardening reflects that (see [security](security.md)).

## How access is wired

```
   ct-ansible ──(SSH, key-only, from="<control IP>"-locked)──┬── every guest CT
        │                                                     └── pve-node-2
        └── pct exec (no SSH) ── used only by the bootstrap scripts on pve-node-1
```

* Each target's `authorized_keys` entry is locked with
  `from="<control IP>",no-agent-forwarding,no-port-forwarding,no-x11-forwarding`.
* Some guests shipped `AllowUsers ssh-user` in sshd, which blocks root *before* the key
  is checked. A drop-in (`/etc/ssh/sshd_config.d/20-ansible.conf`) adds
  `root@<control IP>` to the allow-list on those.
* The two bootstrap scripts
  ([`01-create-control-node.sh`](../ansible/bootstrap/01-create-control-node.sh),
  [`02-deploy-control-node-key.sh`](../ansible/bootstrap/02-deploy-control-node-key.sh))
  build the container and distribute the key. They run on a node as root and use
  `pct exec`, so no SSH is needed to bootstrap SSH.

## Repository layout

```
ansible/
├── ansible.cfg              # inventory path, ssh tuning, yaml stdout
├── inventory/
│   ├── hosts.example.yml    # committed - placeholder addresses, the group structure
│   └── hosts.yml            # gitignored - real addresses + webhook URL
├── roles/
│   ├── apt_upgrade/         # idempotent update+upgrade; tolerates a dead 3rd-party repo
│   ├── pve_node_patch/      # dist-upgrade a node in place; flag if a reboot is due
│   ├── pve_node_reboot/     # drain HA → reboot → wait quorum → un-drain (guarded)
│   └── notify_webhook/      # POST a short summary to the push webhook; never fatal
├── playbooks/
│   ├── group_vars/          # NOTE: beside the playbooks, not the inventory (see below)
│   ├── ping.yml
│   ├── patch-guests.yml
│   ├── patch-hosts.yml
│   └── reboot-hosts.yml
└── bootstrap/               # build + authorise the control container; recreate Semaphore objects
```

### Two non-obvious choices

* **`group_vars/` lives next to the playbooks.** Semaphore runs with its *own* static
  inventory path (because the real `hosts.yml` is gitignored and not in the clone), so
  inventory-adjacent `group_vars` wouldn't load. Beside the playbooks, they load whether
  the run comes from the CLI or from Semaphore.
* **No root `requirements.yml`.** `community.general` and `ansible.posix` come from the
  Debian `ansible` package. A root `requirements.yml` would make Semaphore pull newer
  major versions from Galaxy every run - and `community.general` ≥ 12 removed the `yaml`
  stdout callback, which would break the output format. The pinned reference list is
  kept at `ansible/docs/requirements.reference.yml` for a non-Debian control box.

## Semaphore

[Semaphore CE](https://github.com/semaphoreui/semaphore) - a single Go binary - runs in
the same container and gives Ansible:

* **task templates** (one per playbook), run with one click or on a schedule;
* **cron schedules** (see [patching](patching.md) for the specific times);
* **run history** with full per-run stdout, kept indefinitely - this is the run log,
  `ansible.cfg` deliberately sets no `log_path`;
* **failure alerts** for the case where a playbook errors *before* its own notify step.

It uses a SQLite backend (2.19 dropped BoltDB) and a static YAML inventory pasted into
the UI (encrypted at rest with `access_key_encryption` - so the config file and the DB
must be backed up together, which the nightly job does). Full build steps:
[`ansible/docs/semaphore.md`](../ansible/docs/semaphore.md).

## How a run flows

`patch-guests.yml`, end to end:

1. **Play 1** (once, on `pve-node-1`): `vzdump` the `backup_protected` containers in
   snapshot mode - a bad upgrade is one `pct rollback` away. Skippable with
   `-e pre_patch_backup=false`.
2. **Play 2** (all guests, `serial: 50%`): `apt-get update` (tolerating a dead
   third-party repo), simulate the upgrade to count packages, `apt dist-upgrade` with
   `needrestart` in batch mode to bounce affected services. Container reboots are
   **opt-in** (`-e allow_reboot=true`).
3. **Play 3** (localhost): build a compact per-guest summary and POST it to the webhook.

Every step records facts (`apt_changed`, `apt_upgraded_count`, `reboot_pending`,
`apt_repo_warnings`) that feed the summary, so the phone push tells you exactly which
guests changed and which want a reboot.

## Adding a host

1. Add it to `inventory/hosts.yml` under `lxc_guests` (and `backup_protected` if it's on
   the backup job).
2. Paste the updated inventory into Semaphore's static inventory too (the price of
   keeping `hosts.yml` out of git).
3. Authorise the control key on it -    `bootstrap/02-deploy-control-node-key.sh` (add the ID to `GUEST_IDS`), plus the
   `20-ansible.conf` sshd drop-in if the guest uses `AllowUsers`.
4. `ha-manager add ct:<id> --state started` and add it to the node-affinity rule.

A `community.general.proxmox` **dynamic inventory** (auto-discovers guests from the PVE
API, group membership from tags) would remove steps 1-2; it's a roadmap item.

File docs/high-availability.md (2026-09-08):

# High availability & replication

The goal: **if `pve-node-1` dies at 3am, everything is running again on `pve-node-2`
within a few minutes, with nobody touching a keyboard** - and when `pve-node-1` comes
back, the guests move home on their own.

This page covers how that works, why the pieces are arranged the way they are, and the
manual procedures for planned maintenance.

## The quorum problem on a 2-node cluster

Proxmox HA will only act while the cluster is **quorate** - more than half of the votes
present. A plain 2-node cluster has 2 votes, so losing one node drops you to 1 of 2, the
survivor's `/etc/pve` goes read-only, and the HA manager refuses to start anything.
That is the opposite of what you want.

The fix is a third vote that lives somewhere else: a **QDevice**. This lab runs
`corosync-qnetd` on the **NAS** (an always-on, low-power box that is already central to
the setup). With it:

```
            votes   normal   pve-node-1 down   NAS/QDevice down
pve-node-1    1        ✓            -                 ✓
pve-node-2    1        ✓            ✓                 ✓
QDevice       1        ✓            ✓                 -             ─────    ─────       ─────             ─────
            total      3          2 of 3            2 of 3   → quorate either way
```

Losing any **one** of the three leaves 2 of 3 - still quorate, HA still works. Losing
two at once is game over, but that is true of any 3-vote cluster.

> The QDevice runs on the storage/cluster segment (`10.0.1.x`). If its address ever
> changes, `corosync.conf`'s `quorum.device.net.host` has to be updated and
> `config_version` bumped - pmxcfs then syncs it to both nodes. `pvecm status` should
> show `Qdevice` with `1` vote and an `A,V` (Alive, Voting) flag.

See [`hardware/qdevice-host.md`](../hardware/qdevice-host.md).

## Why the guest disks are on shared storage

HA failover means **either node must be able to start any guest**. On a cluster with no
shared block storage (no Ceph, no SAN), the only way to get there is to put the guest
disk images somewhere both nodes can read: the **NFS export from the NAS** (`PROX-NFS`).

Every guest's root disk is a raw image file on that export. When the HA manager restarts
a guest on `pve-node-2`, the disk is simply already there. There is no replication lag
and nothing to sync, because there is only ever one copy of the disk and both nodes
mount the same filesystem.

This is a deliberate trade: **shared storage buys transparent failover, at the cost of
making the NAS a single point of failure.** Mitigations and the local-storage
alternative are covered in [storage](storage.md).

## HA configuration

* **All 9 running guests are HA-managed** (`ha-manager add ct:<id> --state started`).
  The one container that is normally stopped is left out on purpose.
* A single **node-affinity rule** lists every managed guest and marks `pve-node-1` as
  preferred. Normal state: everything on `pve-node-1`, `pve-node-2` idle.
* **Automatic fail-back is on.** When `pve-node-1` returns from an outage, the HA
  manager migrates the guests back to it.

```
          ┌──────────── pve-node-1 (preferred) ────────────┐
   normal │  ct-dashboard ct-torrent ct-media-a ct-media-b  │   pve-node-2: idle
          │  ct-docker ct-gateway ct-indexer-a/b/c          │
          │  ct-ansible ct-app                              │
          └────────────────────────────────────────────────┘
                              │  pve-node-1 fails
                              ▼
          pve-node-2 fences pve-node-1 (watchdog, ~1 min),
          then starts all 9 guests from PROX-NFS (~2-5 min total)
                              │  pve-node-1 returns
                              ▼
          HA manager migrates the 9 guests back to pve-node-1
```

## What a node failure actually looks like

1. `pve-node-1` stops responding (power, kernel panic, yanked cable).
2. `pve-node-2` + the QDevice still have 2 of 3 votes → the survivor stays quorate.
3. After the fence timeout (~1 minute; the dead node self-fences via its hardware
   watchdog) the HA manager declares `pve-node-1`'s guests recoverable.
4. It starts all 9 on `pve-node-2`, reading their root disks straight from `PROX-NFS`.
   Total time to "everything back up" is roughly **2-5 minutes**.
5. When `pve-node-1` reboots and rejoins, fail-back migrates the guests home.

### Residual caveats (known, accepted)

* **Corosync runs a single ring** on the storage segment. Heavy NFS traffic shares that
  link and could in theory disturb the heartbeat. A second corosync link on the LAN is
  on the roadmap - see [networking](networking.md).
* **The media containers bind-mount the (currently offline) media NAS.** They will start
  on either node without it; the mount just has to exist on whichever node runs them.
* **`pve-node-2` has slightly less RAM.** Fine at real-world usage; there is less
  headroom if every guest spikes at once while running on the smaller node.
* **`pve-node-2`'s local root password is independent** of `pve-node-1`'s. Know it ahead
  of time - you may need that node's own web UI during an outage of the other.

## Planned maintenance - draining a node by hand

For anything that needs a node down (a reboot, hardware work), don't just pull it - use
**HA maintenance mode** so the guests migrate off cleanly first:

```bash
# evacuate pve-node-1 onto pve-node-2, live (no guest restarts)
ha-manager crm-command node-maintenance enable pve-node-1

# wait until nothing is left:
watch "ha-manager status | grep 'pve-node-1,'"

# ... do the work, reboot, etc. ...

# hand the guests back (they return because pve-node-1 is preferred)
ha-manager crm-command node-maintenance disable pve-node-1
```

The [patching automation](patching.md) wraps exactly this sequence in
`reboot-hosts.yml`, with a guard so it never evacuates the node that is currently
running the automation container.

## Verifying HA health

```bash
pvecm status                 # Quorate: Yes, total votes 3, Qdevice A,V
ha-manager status            # every ct:<id> "started" on its node
ha-manager status | grep -c started
cat /etc/pve/ha/rules.cfg    # the node-affinity rule lists every managed guest
```

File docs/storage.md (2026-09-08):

# Storage

## The three tiers

| Storage | Backing | Mounted where | Holds |
|---|---|---|---|
| `local-lvm` | LVM-thin on each node's internal NVMe SSD | that node only | the control container; scratch guests; **the restore target** |
| `PROX-NFS` | NFS export from the **NAS** | both nodes, at `/mnt/pve/PROX-NFS` | **every guest root disk**, the nightly backup archives, host-config backups |
| media NAS | a second NAS (SMB/NFS) - currently offline | bind-mounted into the media containers | bulk media library |

There is **no ZFS and no Ceph.** Each node boots from a single consumer SSD carved into
an LVM root, swap, and a thin pool. The thin pool is mostly empty by design - it exists
as headroom and as the place restores land.

## Why the guest disks live on NFS

A 2-node cluster with no shared block storage can't do HA failover unless the guest disk
images are reachable from both nodes. NFS from the NAS is the simplest way to get there:
every container's root disk is a **raw image file** on `PROX-NFS`, so either node can
start any guest with nothing to copy or sync first. This is the foundation the
[high-availability](high-availability.md) design rests on.

## The trade-off, stated plainly

Shared-storage HA means **the NAS is a single point of failure for the whole fleet**:

* The NAS's disks are mirrored, so a single drive failure is survivable.
* Its OS is on a removable card; the data array can be re-assembled independently if the
  card dies.
* But if the *box* goes down, every guest's root disk disappears at once. The NFS mount
  is `hard`, so guests block rather than get I/O errors - they freeze until it's back.

This is accepted for a homelab where the NAS has been reliable and the recovery story
(restore from backup onto `local-lvm`) is tested. The mitigations:

1. **Backups go to the NAS too, but restores are proven to work onto `local-lvm`** - so
   a lost NAS is a rebuild, not a data-loss event, as long as an off-NAS copy of the
   archives exists (see below).
2. **The control container is on `local-lvm`, not NFS** - so the automation that can
   rebuild everything still runs during an NFS outage.
3. **Roadmap: move the small, stateful containers' root disks onto `local-lvm`** and
   keep only bulk data on NFS. Restore testing has confirmed this works; it also removes
   the nightly backup suspend pause (see [backups](backups.md)).

## The backup-copy gap

The nightly `vzdump` archives currently land on the **same NAS** that holds the live
disks. Disk redundancy on that box does not protect against the box itself failing, a
filesystem bug, or a bad delete. Closing this needs a second copy that does not live on
that NAS - a periodic pull to another machine, or Proxmox Backup Server on separate
hardware. This is **parked** until the second (media) NAS is back in service, which is
the intended target. Until then it is the biggest known weakness in the storage design.

## Snapshot capability

Raw images on NFS have **no snapshot support**, which has two consequences:

* `vzdump` falls back to **suspend mode** for running containers whose root disk is on
  NFS - a few seconds of guest pause per nightly backup. Containers that are stopped, or
  whose disk is on `local-lvm`, back up in **snapshot mode** with no pause.
* You can't take an ad-hoc "before I change this" snapshot of an NFS-backed guest. The
  pre-patch `vzdump` in the [automation](automation.md) exists partly to fill that gap.

Moving a guest's disk to `local-lvm` (`pct move-volume <id> rootfs local-lvm`) gives it
real snapshots back, at the cost of pinning it to one node's local disk.

## vzdump temp staging

One non-obvious detail, learned the hard way: `vzdump`'s temp staging directory must be
**local and mode `0711`** (not the default-on-NFS, and never `0700`).

* Staging on the NFS share itself is slow and trips a warning; a local
  `tmpdir` in `/etc/vzdump.conf` is ~40× faster.
* The archiver `tar` runs under the unprivileged-container UID remap and **cannot
  traverse a `0700` root-owned directory** - the backup fails with
  `Cannot open: Permission denied`. `0711` lets it through while keeping the directory
  unlistable.

## Health checks

```bash
pvesm status                       # all storages "active", free space
df -h /mnt/pve/PROX-NFS            # NFS export headroom
lvs                                # local-lvm thin-pool usage per node
smartctl -a /dev/nvme0            # per-node SSD wear + error counters
```

The SSDs report low wear but a high count of **unsafe shutdowns / power cycles** - consistent with unclean power loss. A UPS with automatic graceful shutdown is on the
roadmap; see [`hardware/apc_ups.md`](../hardware/apc_ups.md).

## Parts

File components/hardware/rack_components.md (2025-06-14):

# Rack Build Components

This section details the custom-built physical enclosure and mounting solutions that form the backbone of the homelab. I based my design on the GeekPi 8U rack, I initially planned to purchase it however it was not available in my country and I felt like I could do something pretty similar without breaking the bank. 


## Initial 3D renders



## Build Progress




## Structure & Enclosure

The entire rack structure is custom-built using standard components, providing a sturdy and modular frame.

* **Extruded Aluminum Profiles (20x20mm):**
    * **Description:** The primary structural elements, forming the vertical posts and horizontal cross-members of the rack. Their modular nature allows for precise assembly and future modifications.
    * **Function:** Provides the main frame to which all other components are attached.
* **Corners:**
    * **Description:** Specifically designed connectors for 20x20mm aluminum profiles, providing rigid 90-degree joints for the frame.
    * **Link:** [Amazon UK Link](https://www.amazon.co.uk/dp/B0CPL6DDYH?ref=ppx_yo2ov_dt_b_fed_asin_title)
    * **Function:** Securely joins the aluminum profiles to create the rectangular frame of the rack.
* **M5 T-Slot Bolts and Nuts:**
    * **Description:** Specialized fasteners designed to slide into the T-slots of the aluminum profiles, allowing for versatile attachment of components.
    * **Link:** [Amazon UK Link](https://www.amazon.co.uk/dp/B0CDBY3PHR?ref=ppx_yo2ov_dt_b_fed_asin_title)
    * **Function:** Used to assemble the aluminum frame and attach various accessories, including the rack ears and other mounting solutions.
* **Acrylic Side Panels (Custom Cut):**
    * **Description:** Clear acrylic sheets cut to size, forming the side enclosures of the rack.
    * **Link:** [Plastic Sheets Custom Cut](https://www.plasticsheets.com/clear-acrylic-sheet-cut-to-size/)
    * **Function:** Enclose the rack, providing protection for the internal components while allowing visibility of the hardware.
* **Hard Slot Cover Flat Seal Panel Holders:**
    * **Description:** Lengths of flat seals designed to fit into the aluminum profile slots, potentially used to secure the acrylic panels or cover unused slots for a cleaner look.
    * **Function:** Provides a flush finish and helps secure panels or prevent dust ingress.
* **Top Handles (Aluminum Cabinet Handles):**
    * **Description:** Durable aluminum handles mounted on the top of the rack.
    * **Link:** [AliExpress Link (Similar to provided description)](https://www.aliexpress.com/item/1005004133524750.html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)
    * **Function:** Facilitates easy portability and movement of the entire rack.
* **Wheels (1-inch Small Furniture Caster Wheels):**
    * **Description:** Low-profile rubber caster wheels attached to the base of the rack.
    * **Function:** Allows the rack to be easily moved and repositioned without lifting.

## Rack Mounting Components

Standard and custom solutions are used to mount the hardware within the 10-inch rack frame.

* **10-inch Rack Ears:**
    * **Description:** Standard rack ears designed for 10-inch wide equipment, likely adapted or used with custom mounts for various devices.
    * **Link:** [Amazon UK Link](https://www.amazon.co.uk/dp/B00LFSC3K6?ref=ppx_yo2ov_dt_b_fed_asin_title)
    * **Function:** Provides the mounting points for rack-compatible devices or custom 3D printed brackets that secure devices to the rack's frame.
* **Perforated Aluminum Sheets:**
    * **Description:** 3mm thick sheets with 10mm diameter holes, used for custom shelves or panels.
    * **Function:** Can be cut and shaped to create custom shelves, blanks, or ventilation panels, offering flexible mounting options for non-rack-standard equipment.

## Power Distribution

Efficient power management within the rack is handled by dedicated Power Distribution Units (PDUs).

* **10" 4-Way Horizontal Power Distribution Unit (PDU) Strip UK Miniline:**
    * **Description:** A compact PDU designed for 10-inch racks, featuring 4 UK sockets.
    * **Function:** Provides easily accessible power outlets for the devices within the rack, streamlining cable management.
* **10" SOHO DETACHABLE 1x IEC 3x UK Horizontal Power Unit Strip PDU UPS Rack Mount:**
    * **Description:** Another 10-inch rack-mountable PDU, offering 3 UK sockets and an IEC input, ideal for connecting to a UPS.
    * **Function:** Supplies power to devices and is designed to connect directly to the UPS for protected power distribution.

## 3D Printed Custom Mounts

Several components are integrated into the rack using custom 3D printed solutions, detailed further in the [Custom 3D Prints](3d_prints/README.md) section. These prints provide tailored mounting for specific devices, optimizing space and airflow.

* **Raspberry Pi 3B/4B/5B 10-inch Rack Mount:**
    * **Description:** A custom bracket for securely mounting the Raspberry Pi into a 10-inch rack slot.
    * **Link:** [Printables.com Link](https://www.printables.com/model/1185545-raspberry-pi-3b4b5b-10-inch-rack-mount/files)
* **Sturdy 10-inch Rack Mount for TP-Link TL-SG108:**
    * **Description:** A tailored mount ensuring the TP-Link switch fits neatly into the 10-inch rack.
    * **Link:** [Printables.com Link](https://www.printables.com/model/967188-sturdy-10-inch-rack-mount-for-the-tl-sg108-consume/files)
* **ThinkCentre M720q/M920q Rack Mount:**
    * **Description:** A specific mount for the ThinkCentre Tiny PC, allowing it to be securely installed in the rack.
    * **Link:** [Thingiverse.com Link](https://www.thingiverse.com/thing:6859441)
* **Custom plate for eInk screen:**
    * **Made this one by measuring the screen and printing a mount that fitted it perfectly

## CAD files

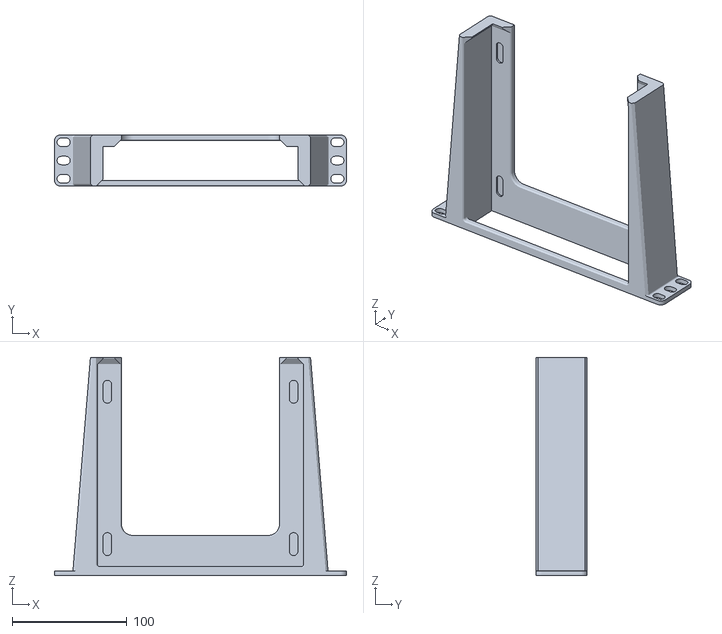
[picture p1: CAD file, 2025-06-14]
3d_prints/Lenovo Thinkcentre Tiny 1U Rack Mount.stl
254.0 x 44.5 x 190.0

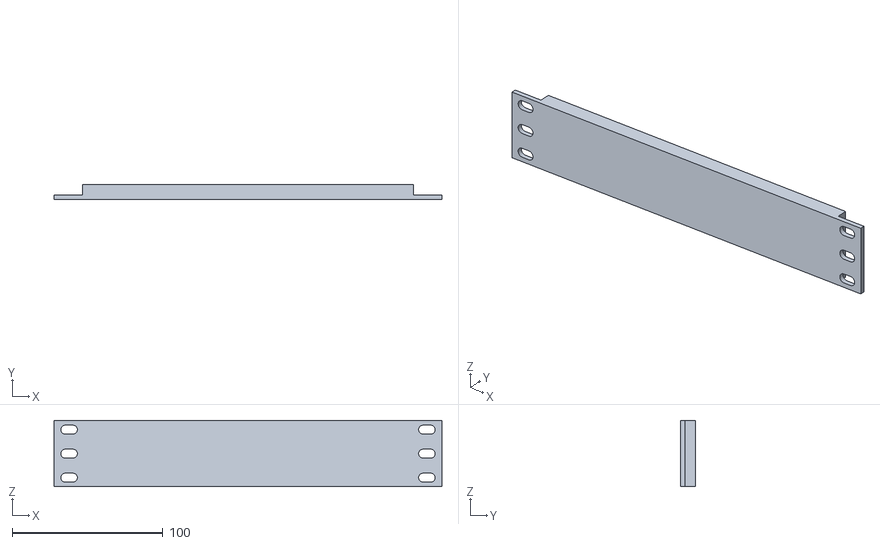
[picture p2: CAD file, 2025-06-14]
3d_prints/10inch_rack_cover.stl
257.0 x 10.0 x 44.0

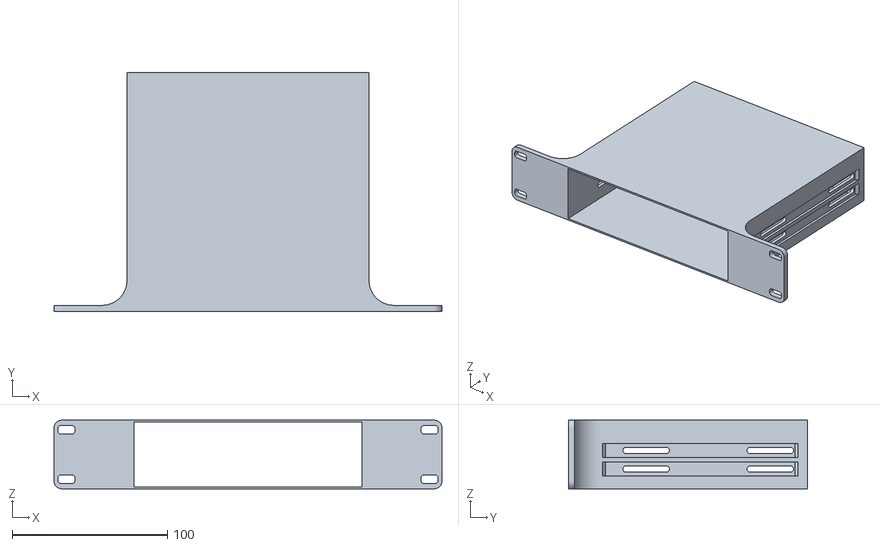
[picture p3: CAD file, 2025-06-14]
3d_prints/5.25_x_1_V1.2.stl
250.0 x 154.0 x 44.2

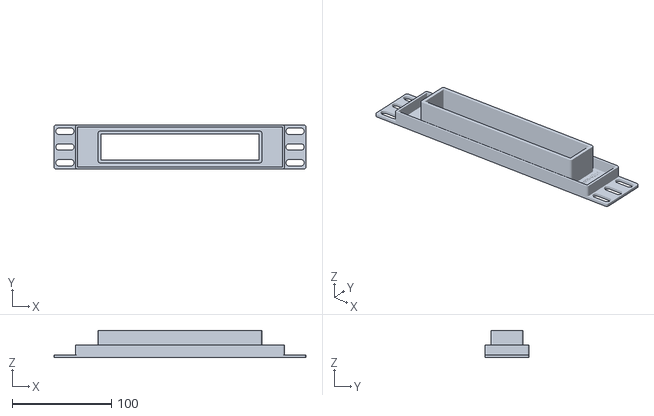
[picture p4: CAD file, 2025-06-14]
3d_prints/10_inch_1U_TL-SG108_mounting_panel.stl
254.0 x 44.5 x 27.5

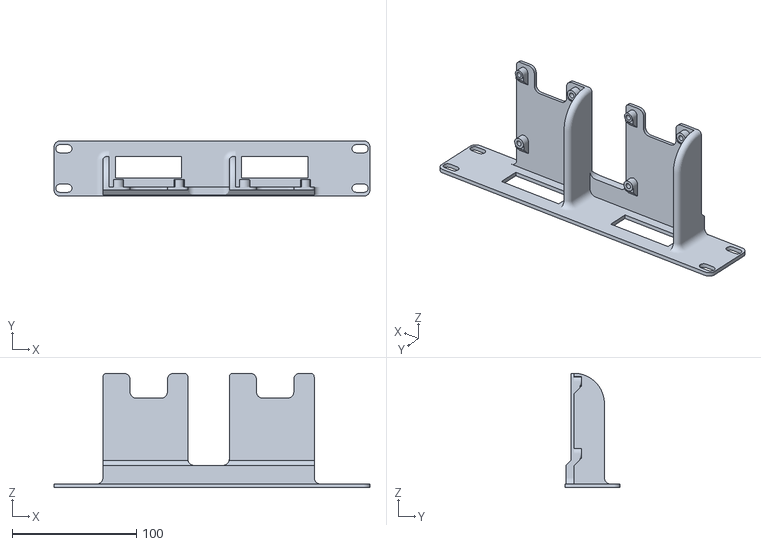
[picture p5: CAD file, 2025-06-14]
3d_prints/rpi-3_4_5b-10i-rm-v1_1.stl
254.0 x 44.5 x 92.0

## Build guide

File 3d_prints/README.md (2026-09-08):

# Custom 3D Prints

This section documents all the custom 3D printed components used in the homelab rack. These prints enable clean integration of non-rack-standard hardware while maximizing space, airflow, and modularity.

All models are either downloaded from trusted sources or custom-designed to fit this specific build.

---

## 3D Printed Parts List

| Component | Source / Link |
|---|---|
| **Raspberry Pi 3B / 4B / 5B Rack Mount** | [Printables.com](https://www.printables.com/model/1185545-raspberry-pi-3b4b5b-10-inch-rack-mount/files) |
| **TP-Link TL-SG108 Switch Mount** | [Printables.com](https://www.printables.com/model/967188-sturdy-10-inch-rack-mount-for-the-tl-sg108-consume/files) |
| **5.25" Drive Adapter Mount** | [Thingiverse](https://www.thingiverse.com/thing:6859441) |
| **ThinkCentre M720q / M920q Mount** | [Printables](https://www.printables.com/model/1040412-lenovo-thinkcentre-tiny-m720qm715qm920q-10-rack-mo) |
| **eInk Display Mount** | Custom-designed for this rack - not publicly uploaded yet, but may be shared later. |

---

## Design Considerations

Each 3D printed part was created or selected with the following goals in mind:

- **Space Optimization**  
  Designed to fit devices snugly in a 10-inch rack, avoiding wasted vertical or horizontal space.

- **Airflow Maintenance**  
  Mounts are open where needed to avoid blocking fans or vents.

- **Modularity & Maintenance**  
  Most mounts are tool-less or use captive screws for easy removal, allowing for hardware swaps or upgrades without tearing down the rack.

---

##  Future Print Ideas

A few designs are in progress or under consideration to further improve the setup:

- Mount for **Eero Mesh 6**
- Enclosure or rack-mount bracket for **ESP32 eInk display**
- **Cable management trays**, clips, or combs specific to the aluminum profile structure

---

## File Access

If you're looking for all print-ready files and design sources, check the repo’s `3d_prints/` directory. Some prints are original; others are remixed from open-source models (attribution included in each subfolder).

---

*Want to remix or contribute your own designs? Feel free to fork the repo or open a PR.*

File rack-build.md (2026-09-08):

# Rack Build Components

This section outlines the custom-built enclosure and mounting setup that forms the physical foundation of my homelab.

Originally, I had planned to buy the **GeekPi 8U Rack**, but it wasn’t available locally. Rather than overpay for shipping or compromise, I decided to build my own version - with a focus on modularity, affordability, and clean design.



---

## Initial 3D Renders

These early mockups helped plan the layout and dimensions before committing to cutting and drilling.




---

## Build Progress

Here’s how things came together during the build process:








---

## Rack Frame & Enclosure Materials

Everything is based on a modular aluminum profile system, with side panels and internal mounts added using a mix of off-the-shelf and custom components.

### Structural Frame

- **Extruded Aluminum Profiles (20x20mm)**  
  The core of the frame - lightweight, strong, and modular.  
  [ebay](https://www.ebay.co.uk/itm/305826763149?var=604998211152)  

- **Corner Connectors**  
  For rigid 90° joints between profiles.  
  [Amazon UK Link](https://www.amazon.co.uk/dp/B0CPL6DDYH?ref=ppx_yo2ov_dt_b_fed_asin_title)  

- **M5 T-Slot Bolts & Nuts**  
  Used throughout for adjustable, tool-free component mounting.  
  [Amazon UK Link](https://www.amazon.co.uk/dp/B0CDBY3PHR?ref=ppx_yo2ov_dt_b_fed_asin_title)  

### Panels & Seals

- **Acrylic Side Panels (Clear, Custom Cut)**  
  Keeps the rack enclosed but visible for aesthetics and protection.  
  [plasticsheets.com](https://www.plasticsheets.com/clear-acrylic-sheet-cut-to-size/)  

- **Flat Seal Panel Holders**  
  Slotted into aluminum rails to hold acrylic securely and help reduce dust ingress.  
  [AliExpress](https://www.aliexpress.com/item/1005003222704634.html?spm=a2g0o.order_list.order_list_main.25.270b1802RzCqnd)

### Mobility & Handling

- **Top-Mounted Aluminum Handles**  
  Makes it easy to move the rack when needed.  
  [AliExpress](https://www.aliexpress.com/item/1005006105161997.html?spm=a2g0o.order_list.order_list_main.15.270b1802RzCqnd)

- **1” Low-Profile Caster Wheels**  
  For smooth repositioning on floors - no heavy lifting required.  
  [AliExpress](https://www.aliexpress.com/item/1005007219086138.html?spm=a2g0o.order_list.order_list_main.5.270b1802RzCqnd)  
---

## Rack Mounting Components

While it's a 10-inch rack footprint, many mounts are custom-made or adapted to fit non-standard devices.

- **10” Rack Ears**  
  Standard rack brackets used in combination with custom prints. They required to be perforated to properly fit into the aluminium profiles.  
  [Amazon UK Link](https://www.amazon.co.uk/dp/B00LFSC3K6?ref=ppx_yo2ov_dt_b_fed_asin_title)  

- **Perforated Aluminum Sheets**  
  3mm thick, 10mm holes. Used to create shelves, blanks, or airflow panels.  
  [ebay](https://www.ebay.co.uk/itm/305840202662?var=605028245526)

---

## Power Distribution

Internal power is handled by compact 10” PDUs designed for SOHO setups.

- **4-Way 10” Horizontal PDU (UK Sockets)**  
  Simple and compact, ideal for powering basic gear.  
  [ebay](https://www.ebay.co.uk/itm/163710047824)

- **10” SOHO PDU with IEC Input (UPS-Ready)**  
  Designed to connect directly to a UPS. Features 3x UK sockets and a detachable cable.  
  [ebay](https://www.ebay.co.uk/itm/186307877455)

- **12V＋5V HDD POWER SUPPLY AC 2A FOR HARD DRIVE MOLEX**  
  This is to provide 12v+5v to the disk enclosure  
  [ebay](https://www.ebay.co.uk/itm/186307877455)

---

## Patching and cable management

- **GeekPi RackMate Patch Panel**   
  [Amazon UK Link](https://amzn.eu/d/7NtIrBL)

- **DIGITUS Cable Entry Panel**  
  [Amazon UK Link](https://amzn.eu/d/53MpwSx)

- **Digitus cable management panel - 10-inch - 1U**  
  [Amazon UK Link](https://amzn.eu/d/9G6zwlS)
  
- **DIGITUS shelf - 1U - 10-inch**  
  This tray is what I use as a mount for my mac mini  
  [Amazon UK Link](https://amzn.eu/d/fQygdA7)

---

## 3D Printed Mounts

A key part of the build - these mounts allow non-rack devices to fit securely and efficiently.

All files and links are documented in the [Custom 3D Prints](3d_prints/README.md) section.

- **Raspberry Pi 3B/4B/5B Rack Mount**  
  [Printables.com](https://www.printables.com/model/1185545-raspberry-pi-3b4b5b-10-inch-rack-mount/files)

- **TP-Link TL-SG108 Switch Mount**  
  [Printables.com](https://www.printables.com/model/967188-sturdy-10-inch-rack-mount-for-the-tl-sg108-consume/files)

- **5.25" Drive Adapter Mount**  
  [Thingiverse](https://www.thingiverse.com/thing:6859441)

- **ThinkCentre M720q/M920q Mount**  
  [Printables.com](https://www.printables.com/model/1040412-lenovo-thinkcentre-tiny-m720qm715qm920q-10-rack-mo)

- **eInk Display Mount**  
  Custom-designed to match the screen dimensions. Not publicly uploaded (yet), but might share it later.  

---

## Summary

This rack was built to be practical, minimal, and tailored to my needs - not just a clone of something from Amazon. Using a mix of aluminum framing, custom-cut panels, and 3D prints, I was able to keep the size down while still allowing for proper rack-mounting and cable management.

Everything is modular and easy to adapt. Whether I’m swapping hardware, expanding storage, or moving the setup to a new room, the enclosure keeps up without needing a full rebuild.

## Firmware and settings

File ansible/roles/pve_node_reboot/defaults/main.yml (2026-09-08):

---
ha_drain_retries: 30
ha_drain_delay: 10
node_reboot_timeout: 900          # cold PVE boot + kernel init can be slow
node_post_reboot_delay: 30
pvecm_quorum_retries: 36
pvecm_quorum_delay: 5
pveproxy_wait_timeout: 180
ha_return_retries: 30
ha_return_delay: 10

# Safety: only reboot a node that actually needs it unless forced.
reboot_only_if_required: true

# The Ansible/Semaphore control node. This playbook runs *inside* it, so it must
# never reboot (or drain) the node currently hosting it - that kills the run.
control_node_vmid: 109
# Set true on the command line ONLY after you have manually moved CT 109 to the
# other node, to let this play reboot the node it used to be on.
control_node_relocated: false

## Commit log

2026-02-25 Fix header formatting in README.md
    Updated section header for future print ideas.
2026-09-08 docs: full revamp — cluster, HA, storage, backups, automation
